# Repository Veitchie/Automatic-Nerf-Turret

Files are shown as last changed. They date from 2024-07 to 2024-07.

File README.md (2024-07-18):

# Automatic NERF Turret

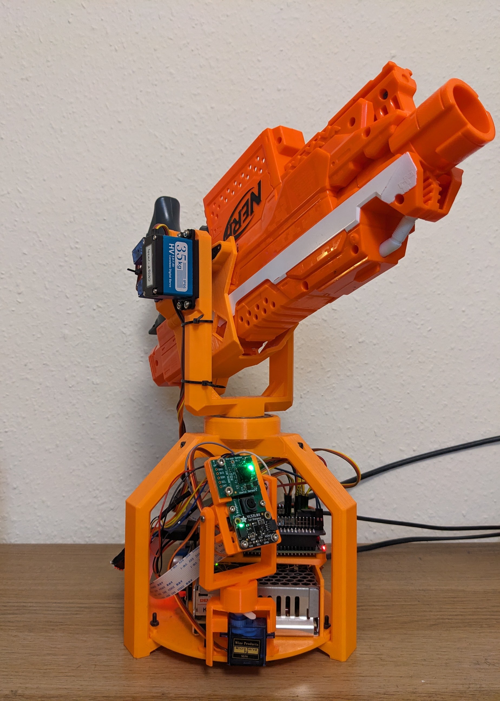
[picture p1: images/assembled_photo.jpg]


#### What's the idea?
To make an automated turret that can do these things:
* Automatically target at least anyone, ideally everyone but me
* Use an unmodified NERF Strife for the shooting, extra points if it's quick-release
* Account for distance real-time by aiming upwards
* 3D print most f not all of the body pieces and brackets

Extra points for me if I add anything else, this is a continuous project.

#### Why did I make this?
I've seen a few NERF turrets over the years, but they usually have the sensors mounted to the barrel which limits their actions, I thought it would be cool to not do that.

## CAD & Code
Both the individual 3d files and an Assembled .STEP file are provided for printing or modification.
Included in the .STEP are models for components like the servos and RPi, some are basic models I made myself while others I sourced online for reference. I have included an [External models](#extModels) section below for crediting and linking to any sources. 

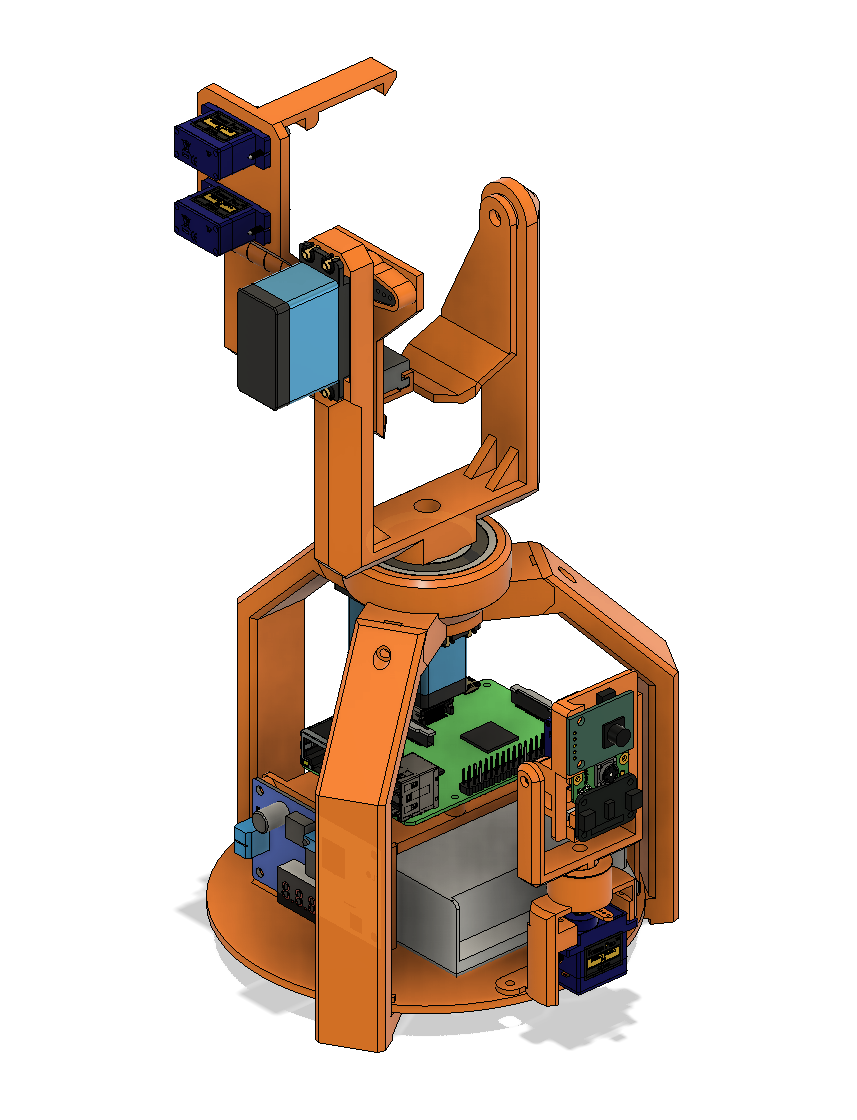
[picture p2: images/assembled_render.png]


### External models 
* [SG90 - Micro Servo 9g - Tower Pro](https://grabcad.com/library/sg90-micro-servo-9g-tower-pro-1) (Modified - I increased the height to match my servos)
* [Raspberry Pi Camera Module v2.1](https://grabcad.com/library/raspberry-pi-camera-4) (Modified - Added ribbon cable)
* [LM2596 DC-DC Buck Converter](https://grabcad.com/library/lm2596-dc-dc-buck-converter-2)
* [Raspberry Pi 2 model B](https://grabcad.com/library/raspberry-pi-2-model-b-3d-cad-assembly-model-2)

### Components used
* VL53L0X LIDAR
* Person Sensor by Useful Sensors
* Raspberry Pi Camera Module v2.1
* 2 x DS3235SG 35Kg 270° Servos
* 4 x SG90 9g Servos
* Raspberry Pi 2 Model B
* Adafruit 16-Channel PWM / Servo HAT for Raspberry Pi
* LM2596 DC-DC Buck Converter
* 6005 25x47x12mm bearing
* 12v Switching Power Supply
* A variety of M3 & M4 bolts and nuts
* NERF Stryfe blaster

### Dependencies
* [Adafruit_CircuitPython_VL53L0X](https://github.com/adafruit/Adafruit_CircuitPython_VL53L0X)
* [Adafruit_CircuitPython_ServoKit](https://github.com/adafruit/Adafruit_CircuitPython_ServoKit)

## My reasoning's for certain decisions

#### Buying components vs. using what I have
My decisions about where to put money in this project seems confusing. I'm basing the build around an old NERF blaster without modifying it and I've limited my computing power to a Raspberry Pi 2, but I also bought a Person Sensor to do facial detection and high torque 35kg servos. The simple answer is I have a lot of random little things, like a Raspberry Pi 2, and I try to do workarounds with what I have first before buying something else; it's cheaper & easier to buy a Person Sensor and use an old RPi than it is to try and get a new one have you seen the prices?!

#### What's with the massive bearing?
The 6005 bearing is both overkill for the weight of a plastic NERF blaster, and the direction of forces on the bearing. My main reasons for using it is that it's centre diameter is nice and big, and it's significantly smoother than bare plastic.

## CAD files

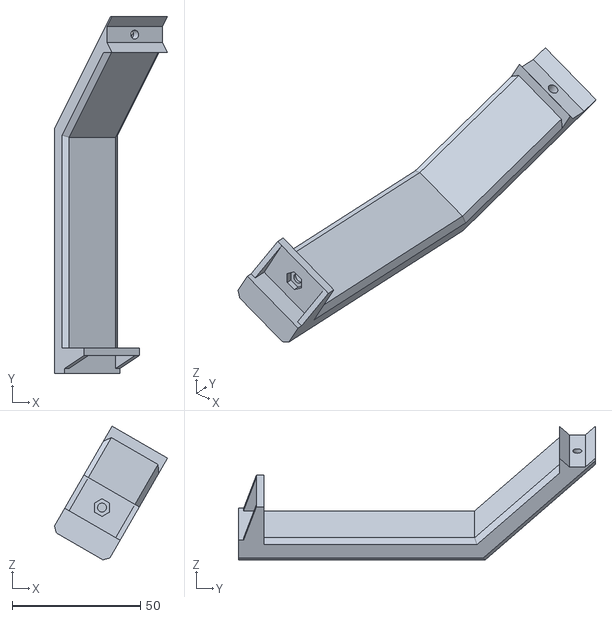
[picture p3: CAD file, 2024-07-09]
models/turret_leg.stl
44.1 x 139.3 x 52.2

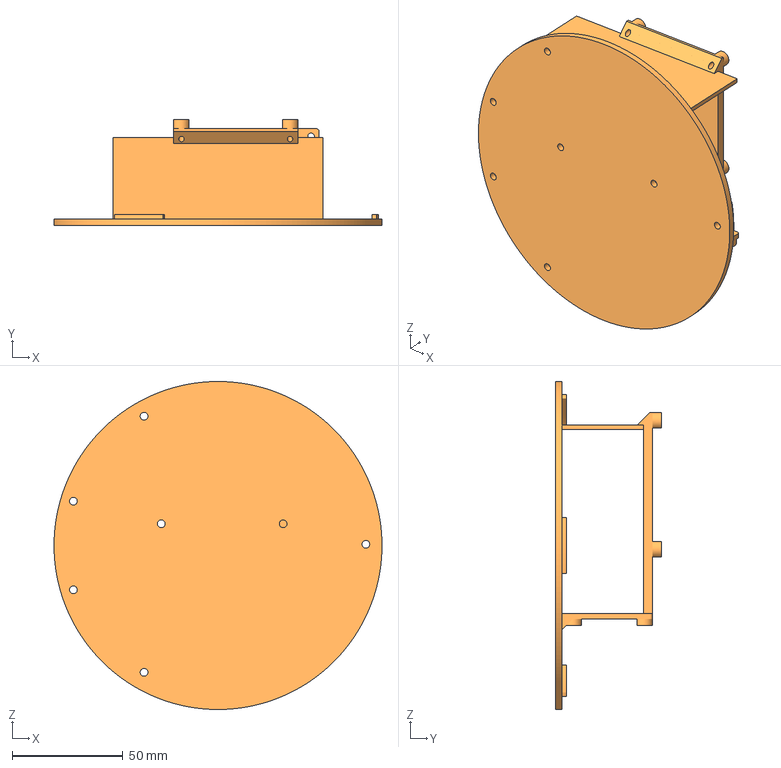
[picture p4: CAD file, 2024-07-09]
models/turret_base_plate.3mf
148.0 x 48.0 x 148.0 mm

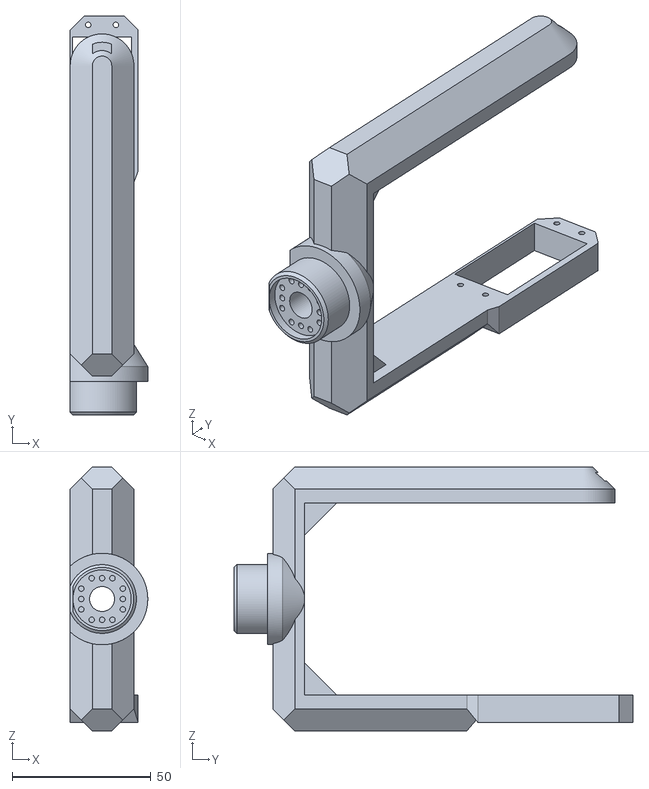
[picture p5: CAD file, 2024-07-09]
models/turret_fork.stl
28.0 x 144.0 x 95.2

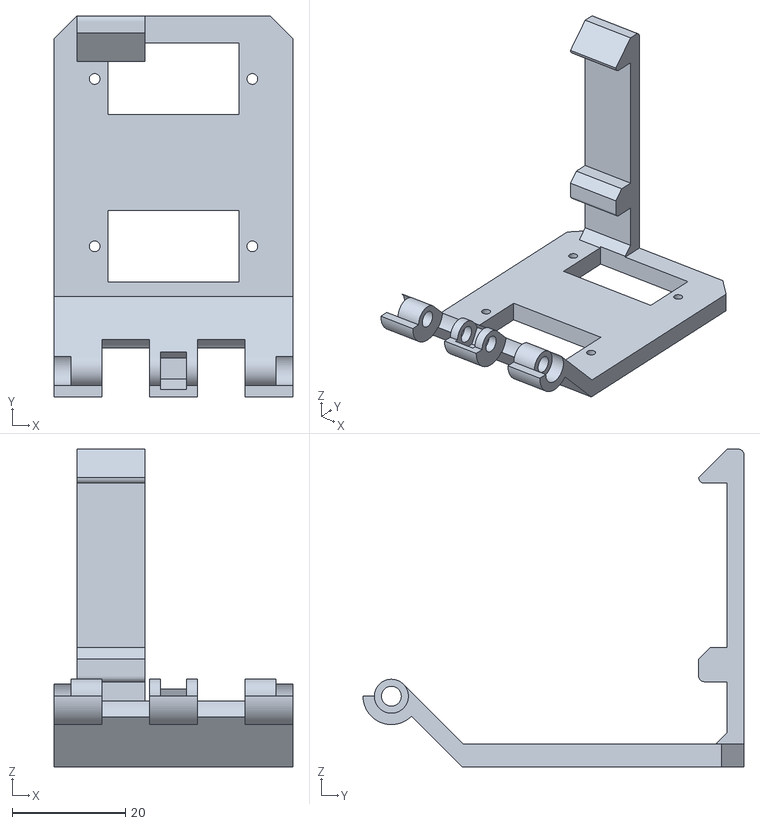
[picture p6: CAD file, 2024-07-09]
models/turret_trigger_plate.stl
42.1 x 67.1 x 56.0

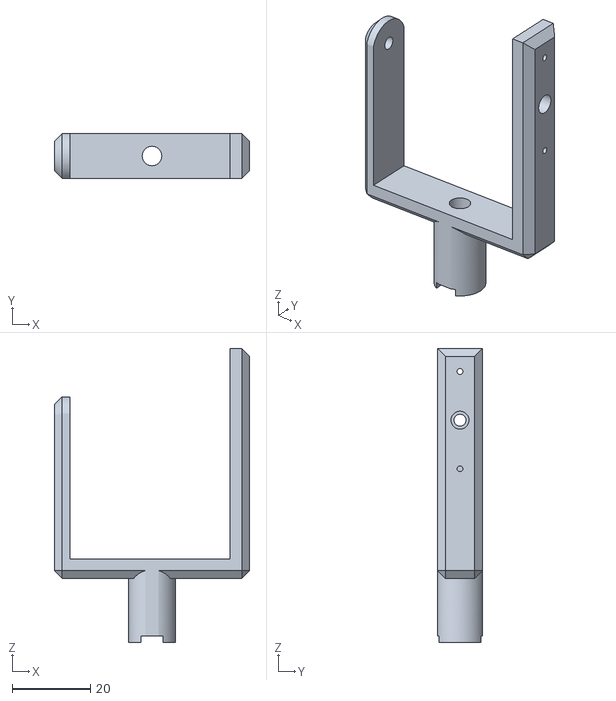
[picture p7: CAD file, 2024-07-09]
models/tracking_fork.stl
50.0 x 11.5 x 75.3

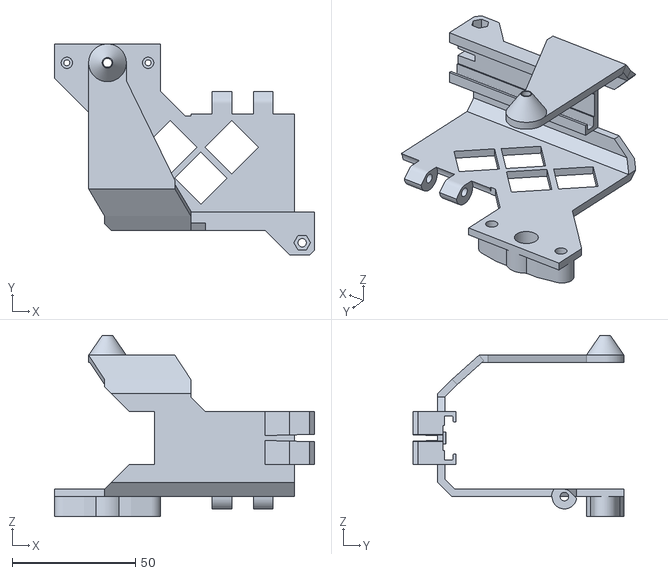
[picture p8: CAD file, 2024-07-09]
models/turret_gun_mount.stl
105.5 x 85.7 x 73.5

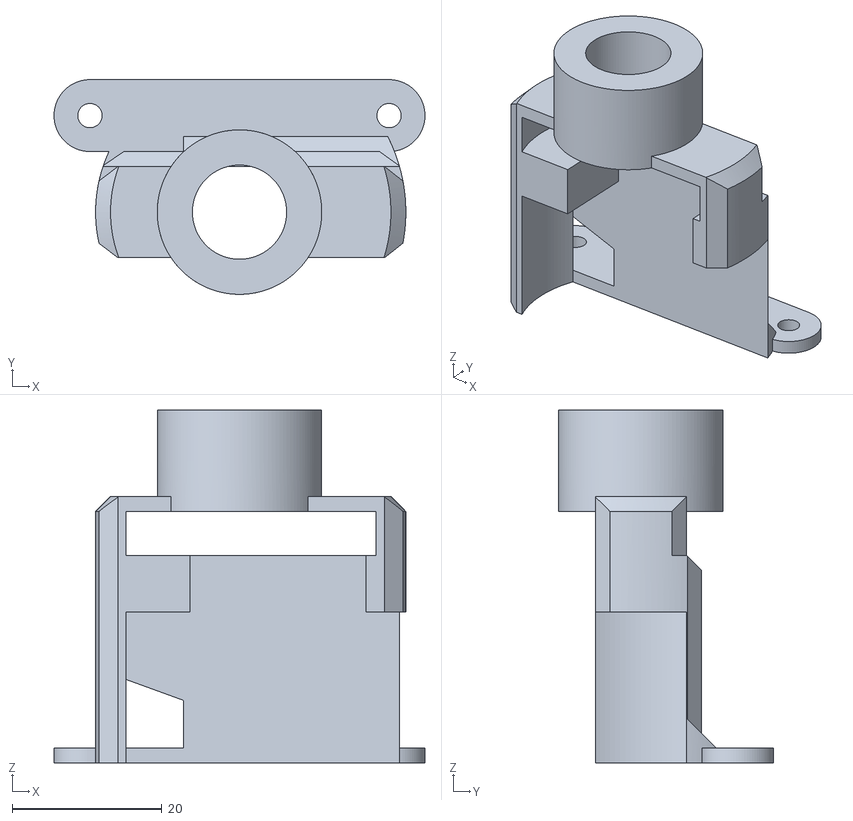
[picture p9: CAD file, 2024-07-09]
models/tracking_base.stl
49.6 x 28.7 x 47.2

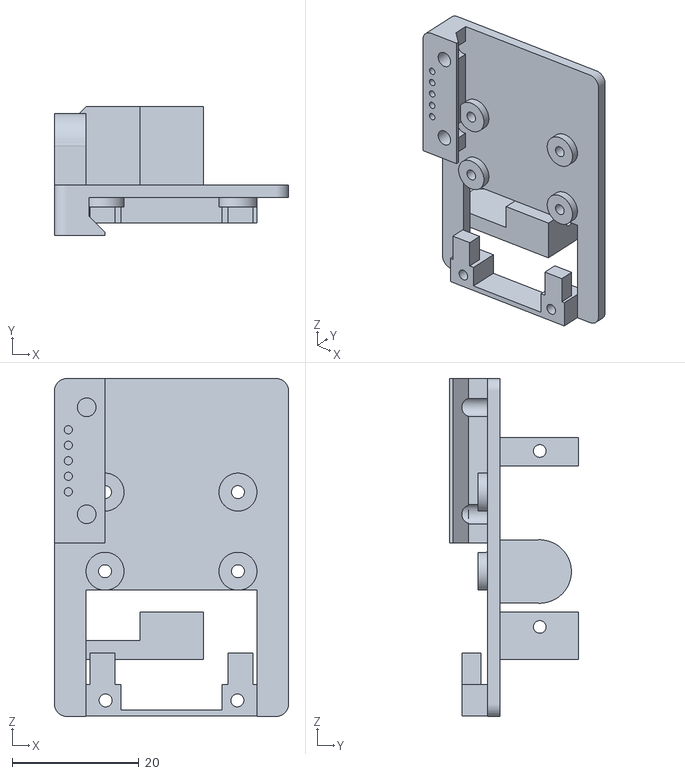
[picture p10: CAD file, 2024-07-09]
models/tracking_sensor_plate.stl
37.0 x 20.4 x 53.4

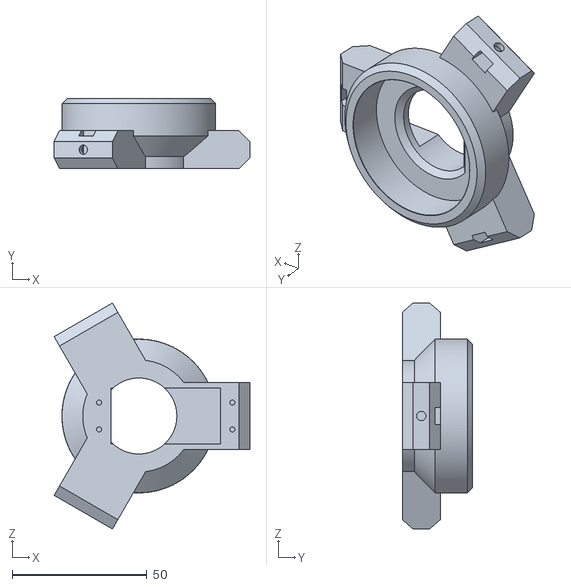
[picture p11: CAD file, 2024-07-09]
models/turret_collar.stl
72.7 x 26.1 x 83.9

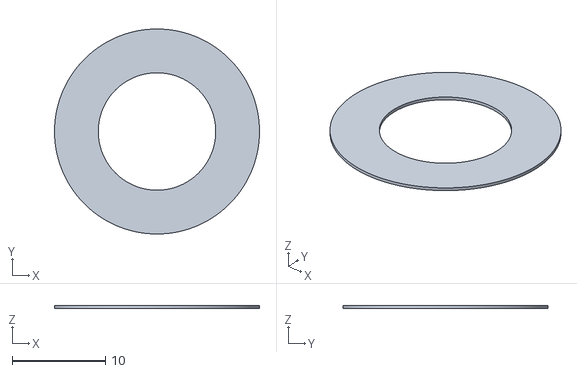
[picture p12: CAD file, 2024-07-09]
models/tracking_washer.stl
22.0 x 22.0 x 0.3

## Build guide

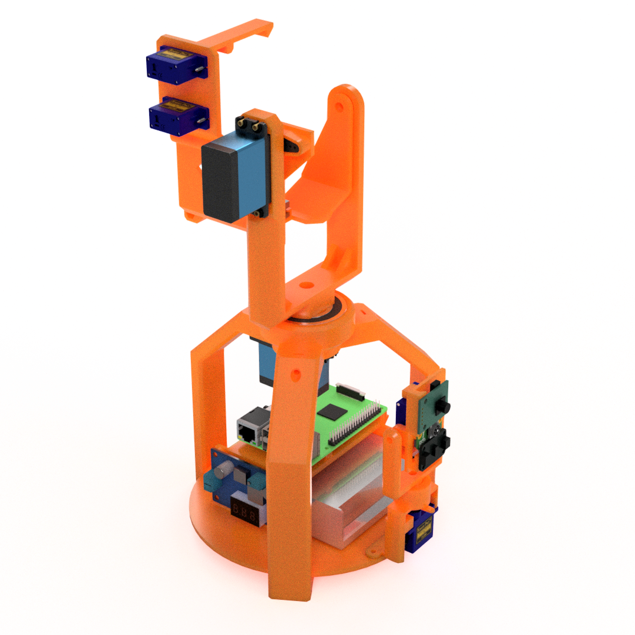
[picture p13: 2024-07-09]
images/assembled_CAD.png

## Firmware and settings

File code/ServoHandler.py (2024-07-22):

from CustomServo import Servo
from adafruit_servokit import ServoKit
import threading
from timeit import default_timer as timer
import time

class ServoHandler:
    
    def __init__(self, debug = False):
        self.kit = ServoKit(channels=16)
        
        self.debug = debug
        
        self.gunYaw = Servo(self.kit.servo[0], dom=270, minPulse=400, maxPulse=2500, minAngle=0, maxAngle=270, restAngle=135, maxSpeed=250, acceleration=2000, adjustment=-10)
        self.gunYPitch = Servo(self.kit.servo[1], dom=270, minPulse=400, maxPulse=2500, minAngle=60, maxAngle=120, restAngle=90, maxSpeed=250, acceleration=2000)
        
        self._prime = Servo(self.kit.servo[2], dom=180, minPulse=500, maxPulse=2500, minAngle=10, maxAngle=170, restAngle=90, maxSpeed=250, acceleration=2000)
        self._trigger = Servo(self.kit.servo[3], dom=180, minPulse=500, maxPulse=2500, minAngle=10, maxAngle=170, restAngle=130, maxSpeed=250, acceleration=2000)

        self.trackYaw = Servo(self.kit.servo[4], dom=180, minPulse=500, maxPulse=2500, minAngle=10, maxAngle=170, restAngle=90, maxSpeed=250, acceleration=2000, invert=True, name = "trackYaw")
        self.trackPitch = Servo(self.kit.servo[5], dom=180, minPulse=500, maxPulse=2500, minAngle=10, maxAngle=170, restAngle=90, maxSpeed=250, acceleration=2000, adjustment=20, name = "trackPitch")
        
        timerStartValue = timer()

        self._primed = False
        self.__triggerPull = False
        self.__triggerDepressionDelay = 0.5
        self.__triggerPullAngle = 55
        self.__primeActiveAngle = 50
        self.__revTimer = timerStartValue
        self.__triggerReleaseTime = timerStartValue
        self.__spinupTime = 2
        self.__maxSpin = False

        self.enabled = False
        self.exit = False
        
        self.forwardOffset = 10
        self.rightOffset = 0
        self.heightOffset = 20
        
        self.timeAtLastUpdate = timerStartValue
        self.updateTime = 0.01
        self.updateThread = threading.Thread(target=self.update, args=(), daemon=True)
        self.start()
    
    def enable(self):
        self.enabled = True
        
    def disable(self):
        self.enabled = False

    def start(self):
        self.exit = False
        self.updateThread.start()
        
    def stop(self):
        self.exit = True
    
    def moveTurret(self, angles):
        a = self.gunYaw.setAngle(angles[0])
        b = self.gunYPitch.setAngle(angles[1])
        return a or b
        
    def adjustCamera(self, angles):
        self.trackYaw.adjust(angles[0])
        self.trackPitch.adjust(angles[1])
        
    def setCamera(self, angles):
        self.trackYaw.setAngle(angles[0])
        self.trackPitch.setAngle(angles[1])
    
    def fromCentre(self, angles):
        self.trackYaw.setAngle(self.trackYaw.getCurrentAngle() - self.trackYaw.adjustment + angles[0])
        self.trackPitch.setAngle(self.trackPitch.getCurrentAngle() - self.trackPitch.adjustment + angles[1])
        
    
    def update(self):
        while (not self.exit):
            currentTime = timer()

            if (self.enabled):

                if self._primed:
                    elapsedTime = currentTime - self.__revTimer
                    if elapsedTime > self.__spinupTime:
                        self.__maxSpin = True
                    if self.__triggerPull:
                        timeSinceTriggerPull = currentTime - self.__triggerPullTime
                        if timeSinceTriggerPull > self.__triggerDepressionDelay:
                            self._trigger.rest()
                            self.__triggerPull = False
                            self.__triggerReleaseTime = timer()
                        else:
                            self._trigger.setAngle(self.__triggerPullAngle)


                self.gunYaw.update()
                self.gunYPitch.update()
                self.trackYaw.update()
                self.trackPitch.update()
                self._prime.update()
                self._trigger.update()

            if (self.debug):
                print("ServoHandler: track-target-angle -> [%s,%s]" % (self.trackYaw.targetAngle,self.trackPitch.targetAngle))
            
    
    def inMotion(self):
        return not (self.trackYaw.atPos and self.trackPitch.atPos)
    
    def prime(self, noTimerUpdate = False):
        if not noTimerUpdate and self._primed:
            self.__revTimer = timer()
        self._prime.setAngle(self.__primeActiveAngle)
        self._primed = True
        
    def unprime(self):
        self._primed = False
        self.__maxSpin = False
        self.__triggerPull = False
        self._prime.rest()

    def fire(self):
        self.prime(noTimerUpdate = True)
        if not self.__triggerPull:
            self.__triggerPullTime = timer()
        if self.__maxSpin and (timer() - self.__triggerReleaseTime) > self.__triggerDepressionDelay:
            self.__triggerPull = True


if __name__ == '__main__':
    servoHandler = ServoHandler()
    servoHandler.enable()

    x = ""
    a = 10
    while not x == "c":

        x = input()
        if x == "p":
            servoHandler.unprime()
        if x == "":
            servoHandler.fire()
    servoHandler.unprime()

    time.sleep(1)

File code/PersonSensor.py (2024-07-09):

# Example of accessing the Person Sensor from Useful Sensors on a Pi using
# Python. See https://usfl.ink/ps_dev for the full developer guide.

import io
import fcntl
import struct
import time
from threading import Thread


class PersonSensor:
    
    def __init__(self):

        # The person sensor has the I2C ID of hex 62, or decimal 98.
        PERSON_SENSOR_I2C_ADDRESS = 0x62

        # We will be reading raw bytes over I2C, and we'll need to decode them into
        # data structures. These strings define the format used for the decoding, and
        # are derived from the layouts defined in the developer guide.
        self.PERSON_SENSOR_I2C_HEADER_FORMAT = "BBH"
        self.PERSON_SENSOR_I2C_HEADER_BYTE_COUNT = struct.calcsize(self.PERSON_SENSOR_I2C_HEADER_FORMAT)

        self.PERSON_SENSOR_FACE_FORMAT = "BBBBBBbB"
        self.PERSON_SENSOR_FACE_BYTE_COUNT = struct.calcsize(self.PERSON_SENSOR_FACE_FORMAT)

        PERSON_SENSOR_FACE_MAX = 4
        PERSON_SENSOR_RESULT_FORMAT = self.PERSON_SENSOR_I2C_HEADER_FORMAT + "B" + self.PERSON_SENSOR_FACE_FORMAT * PERSON_SENSOR_FACE_MAX + "H"
        self.PERSON_SENSOR_RESULT_BYTE_COUNT = struct.calcsize(PERSON_SENSOR_RESULT_FORMAT)

        # I2C channel 1 is connected to the GPIO pins
        I2C_CHANNEL = 1
        I2C_PERIPHERAL = 0x703

        # How long to pause between sensor polls.
        self.PERSON_SENSOR_DELAY = 0.2 * 0.98

        self.i2c_handle = io.open("/dev/i2c-" + str(I2C_CHANNEL), "rb", buffering=0)
        fcntl.ioctl(self.i2c_handle, I2C_PERIPHERAL, PERSON_SENSOR_I2C_ADDRESS)
        
        
        # Custom variables
        self.continousEnabled = False
        self.fov = 110
        resolution = [1280,720]
        self.fovScale = [self.fov / 255, (self.fov * (resolution[1] / resolution[0])) / 255]
        self.faces = -1
        self.previousValue = [0,0]
        
        self.sensorCutoff = [[60,255],[60,255]]
        self.adjustedCentre = [self.sensorCutoff[0][0] + ((self.sensorCutoff[0][1] - self.sensorCutoff[0][0]) / 2), self.sensorCutoff[1][0] + ((self.sensorCutoff[1][1] - self.sensorCutoff[1][0]) / 2)]
        
        self.start()
        
    
    def start(self):
        self.continousEnabled = True
        Thread(target=self.continousUpdate, args=(), daemon=True).start()
    
    def stop(self):
        self.continousEnabled = False
    
    def continousUpdate(self):
        while self.continousEnabled:
            self.faces = self.update()
            #time.sleep(self.PERSON_SENSOR_DELAY)
            
    def update(self):
        """
        Grabs data and creates an array of faces (dictionaries), the array is saved to self.faces and returned by the function
        
        Parameters:
            NONE
        Returns:
            When faces are detected:
                Array of faces
            WHen no faces are detected:
                -1
        """
        attemptingConnection = True
        while attemptingConnection:
            try:
                read_bytes = self.i2c_handle.read(self.PERSON_SENSOR_RESULT_BYTE_COUNT)
                break
            except OSError as error:
                print("No person sensor data found")
                print(error)
                time.sleep(self.PERSON_SENSOR_DELAY)
        offset = 0
        (pad1, pad2, payload_bytes) = struct.unpack_from(self.PERSON_SENSOR_I2C_HEADER_FORMAT, read_bytes, offset)
        offset = offset + self.PERSON_SENSOR_I2C_HEADER_BYTE_COUNT

        (num_faces) = struct.unpack_from("B", read_bytes, offset)
        num_faces = int(num_faces[0])
        offset = offset + 1
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

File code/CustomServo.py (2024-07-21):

from timeit import default_timer as timer

class Servo:
    """
    A custom servo clas built to expand the Adafruit ServoKit library
    """
    
    def __init__(self, servo,
        dom = 180, 
        minPulse = 500, maxPulse = 2500,
        minAngle = 0, maxAngle = 180,
        restAngle = 90,
        maxSpeed = 250,
        acceleration = 2000,
        adjustment = 0,
        invert = False,
        name = "generic-servo"):
        """
        Servo setup.
        
        Parameters:
            servo (servokit.servo[index]): The associated servo on the servokit. MANDATORY
            dom (int): The servos maximum range of motion.
            minPulse (int): Pulse width that achieves the servos minimum angle.
            maxPulse (int): Pulse width that achieves the servos maximum angle.
            restAngle (int): Resting angle of the servo.
            maxSpeed (int): Maximum speed limit of the servo (degrees per second).
            acceleration (int): Acceleration/decceleration rate (degrees per second per second).
            adjustment (int): Servo horn ange adjustment.
            invert (bool): Inverts the servo if it moves the wrong way.
        """
        
        # Establish all parameters of the servo
        self.servo = servo
        self.dom = dom
        self.minPulse = minPulse
        self.maxPulse = maxPulse
        self.minAngle = minAngle
        self.maxAngle = maxAngle
        self.restAngle = restAngle
        self.maxSpeed = maxSpeed
        self.invert = invert
        self.name = name
        
        # Set degrees of motion (pulse band is spread across this range of motion)
        self.servo.actuation_range = dom
        self.servo.set_pulse_width_range(minPulse, maxPulse)
        
        # Variables of the servo
        self.acceleration = acceleration
        self.currentJump = 0
        self.currentSpeed = 0
        self.prevSpeed = 0
        self.currentAngle = self.restAngle
        self.targetAngle = self.currentAngle
        self.servo.angle = self.restAngle
        self.direction = 0
        self.adjustment = adjustment
        self.atPos = False
        self.targetFrozen = False
        
        self.timeAtLastUpdate = timer()
    
    
    def getDirection(self, current, target):
        if (current == target):
            return 0
        return (target - current) / abs(target - current)
    
    
    def setAngle(self, target):
        """
        Returns:
            self.update() : If the Update thread crashes, this will continue to move the servo without acceleration
        """
        target = target + self.adjustment
        target = min(target, self.maxAngle)
        target = max(target, self.minAngle)
        
        if (self.invert):
            target = self.dom - target
        
        self.direction = self.getDirection(self.currentAngle, target)
        self.targetAngle = target
        #print("CustomServo-setAngle: Setting %s's targetAngle to %s" % (self.name,target))
        self.atPos = False
        return self.update()
    
    def rest(self):
        self.setAngle(self.restAngle)
    
    
    def adjust(self, val):
        self.setAngle(self.targetAngle + val)
    
    
    def update(self):
        self.atPos = False
        
        currentUptime = timer()
    
        timeElapsed = currentUptime - self.timeAtLastUpdate
        self.timeAtLastUpdate = currentUptime
        
        targetAngle = self.targetAngle
        
        if (self.currentAngle == targetAngle or abs(self.currentAngle - targetAngle) < 1):
            self.currentSpeed = 0
            
            self.atPos = True
            return True
        
        else:
        
            distanceToTarget = abs(targetAngle - self.currentAngle)
            
            decelerationDistance = ( self.prevSpeed ** 2 ) / ( 2 * self.acceleration )
            
            decel = False
            
            if (distanceToTarget > decelerationDistance):
            
                self.currentSpeed += self.acceleration * timeElapsed * self.direction  #Increase speed
                
            else:
                
                self.currentSpeed -= self.acceleration * timeElapsed * self.direction
                
                decel = True
            
            if (abs(self.currentSpeed) > self.maxSpeed):
                self.currentSpeed = self.maxSpeed * (self.currentSpeed / abs(self.currentSpeed))
            
            self.currentJump = self.currentSpeed * timeElapsed
            
            if (abs(self.currentJump) >= abs(self.currentAngle - targetAngle) ): # Check if the next planned move will take us past the target angle
            
                self.currentAngle = targetAngle
                
                self.currentSpeed = 0
            
            else:
                
                self.currentAngle += self.currentJump
                
                self.currentAngle = min(self.currentAngle, self.maxAngle)
                self.currentAngle = max(self.currentAngle, self.minAngle)
                

        #print("CustomServo-update: Moving %s to %s" % (self.name, self.currentAngle))
        self.servo.angle = self.currentAngle # Move servo to currentAngle
        self.prevSpeed = self.currentSpeed
           
            
        return self.atPos
        
        
    def setAdjustment(self, angle):
        self.adjustment = angle
        self.setAngle(self.targetAngle)
        
    def getCurrentAngle(self):
        if (self.invert):
            return self.dom - self.servo.angle
        return self.servo.angle

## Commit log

2024-07-09 Images and model dump
    [tracking_base.stl, tracking_fork.stl, tracking_sensor_plate.stl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]
2024-07-12 Added servo 9g and Pi Cam to readme
2024-07-18 assembled photo
2024-07-18 LIDAR test file
2024-07-19 completed LIDAR init
2024-07-19 Added new LIDAR to handler
2024-07-20 LIDARsetup cleanup
2024-07-21 Motor priming setup
2024-07-21 Fixed typo in unused (for now) code
    [CustomServo.py]
2024-07-22 fixed some trigger edge-cases
    [ServoHandler.py]
